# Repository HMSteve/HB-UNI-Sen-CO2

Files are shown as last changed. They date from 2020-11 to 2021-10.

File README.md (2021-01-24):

# HB-UNI-Sen-CO2

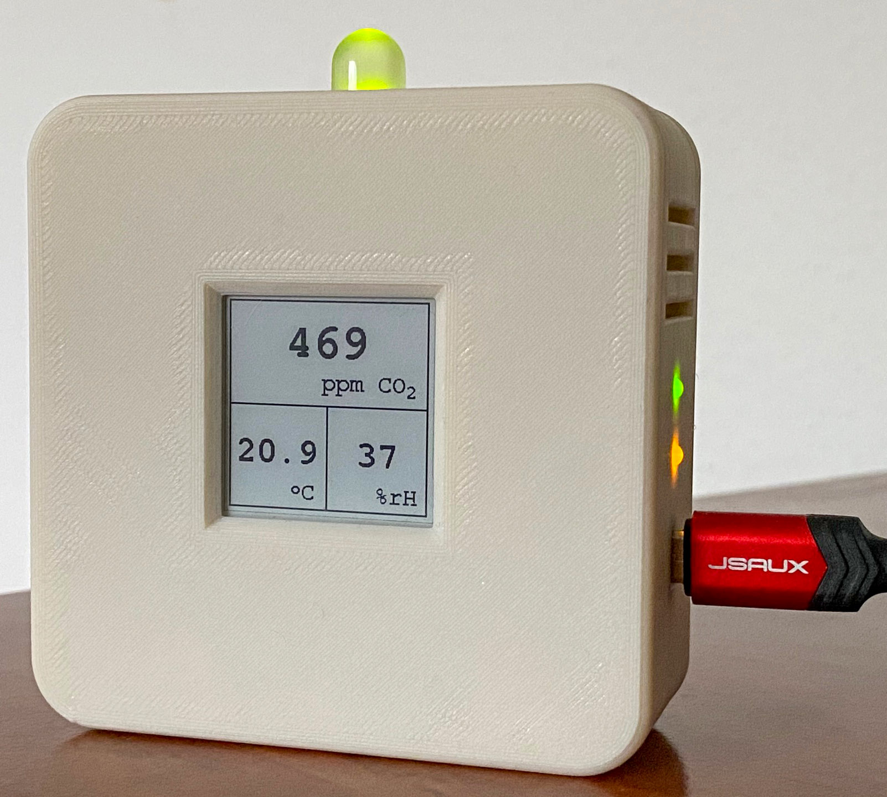
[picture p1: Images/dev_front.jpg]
HB-UNI-Sen-CO2


Eine AskSinPP-Implementierung eines Innenraum-Sensors mit dem NDIR-CO2-Sensor SCD30. Das Geraet kann regulaer in eine Homematic-Umgebung eingebunden werden und liefert Messwerte fuer die CO2-Konzentration, Temperatur, Lueftfeuchte und bei bestuecktem BME280 auch Luftdruck. Ebenso kann es abseits einer Homematic-Installation stand-alone als "CO2-Ampel" verwendet werden: Die Messwerte werden auf einem E-Paper-Display angezeigt und es kann eine Indikator-LED fuer die CO2-Konzentration zugeschaltet werden. Der Betrieb erfolgt mittels zweier AA-NiMH-Akkus, auf Li-Po/Li-Ionen-Akkus wurde unter Sicherheitsaspekten bewusst verzichtet. Eine Ladeschaltung mit Micro-USB-Buchse ist eingebaut. Ueber diese erfolgt eine Schnelladung mit 500mA sowie auf Wunsch parallel zu einer "Erhaltungsladung" die dauerhafte Versorgung des Sensors. Hierzu dient ein uebliches USB-Ladegeraet, das mind. 1A dauerhaft liefern koennen sollte.

## Platine

Auf der Platine sind drei I2C-Steckplaetze fuer Sensoren vorgesehen. Neben dem [Sensirion SCD30](https://www.sensirion.com/de/umweltsensoren/kohlendioxidsensor/kohlendioxidsensoren-co2/) bietet sich ein [4-poliges BME280-Modul](https://www.ebay.de/itm/BME280-Temperatur-Luftdruck-Feuchtigkeit-Sensor-I2C-1-8-5V-Modul/114603492524) zur Luftdruck-Kompensation an. Der Drucksensor ist auch in der Firmware vorgesehen. Der dritte Steckplatz ist aktuell frei.
Als Display findet ein [1.54" Waveshare-E-Paper-Modul](https://www.waveshare.com/1.54inch-e-Paper-Module.htm) Verwendung.

[Schaltplan](https://github.com/HMSteve/HB-UNI-Sen-CO2/blob/main/PCB/HB-Uni-Sen-CO2_Schematic.pdf)

[Stueckliste](https://github.com/HMSteve/HB-UNI-Sen-CO2/blob/main/PCB/HB_UNI_Sen_CO2_BOM.pdf)

Ein paar Fotos vom Aufbau:

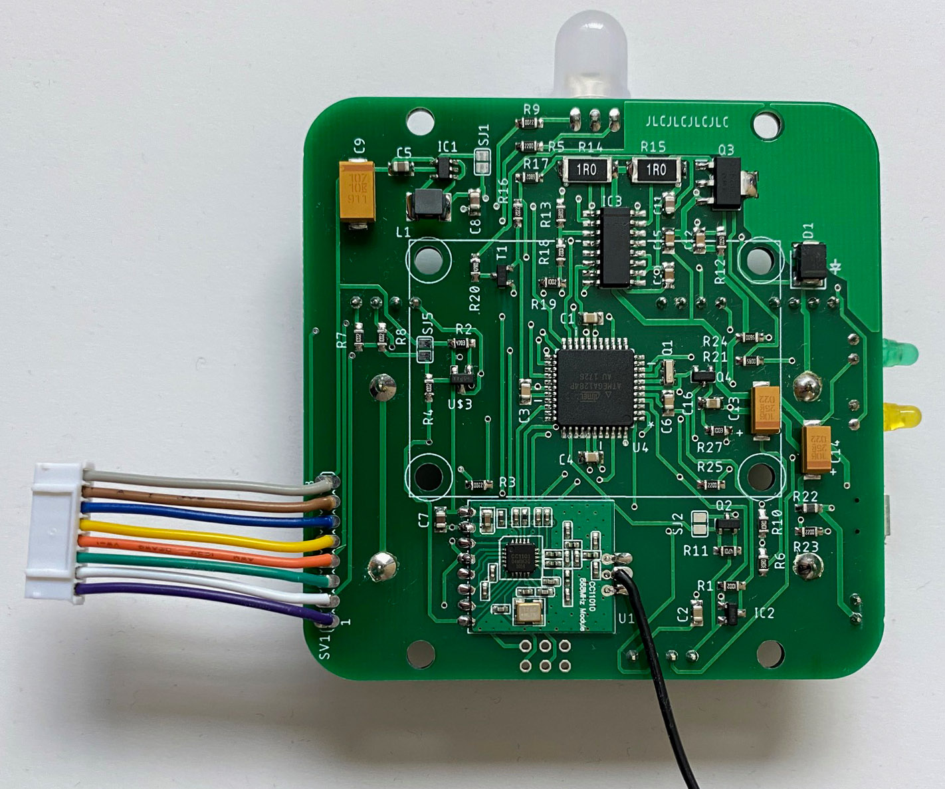
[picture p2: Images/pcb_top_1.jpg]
PCB Top


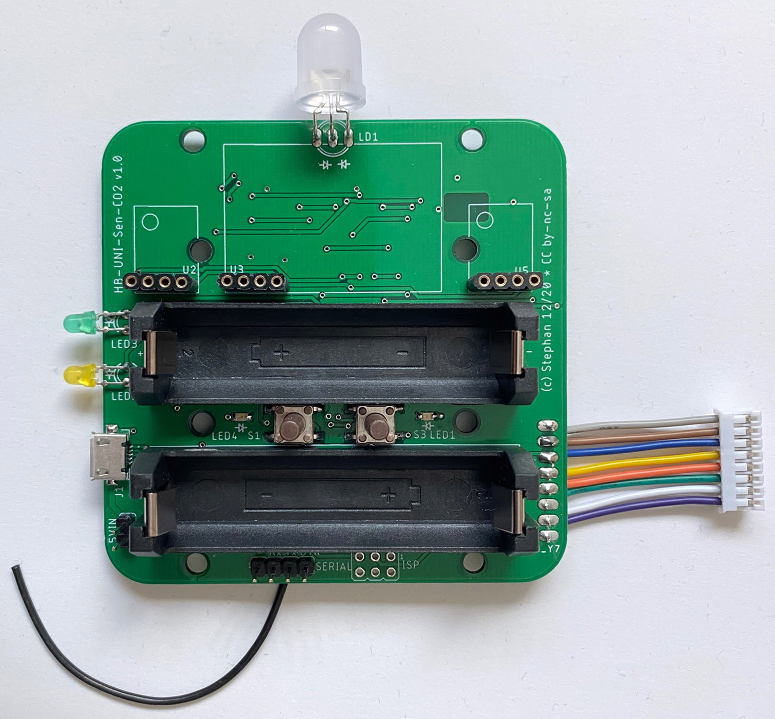
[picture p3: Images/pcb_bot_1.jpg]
PCB Bottom


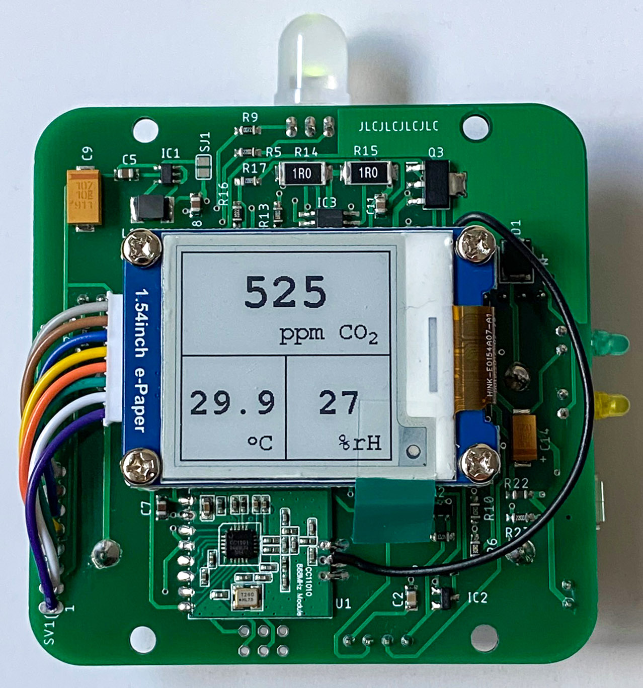
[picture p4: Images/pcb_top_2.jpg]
PCB Top 2


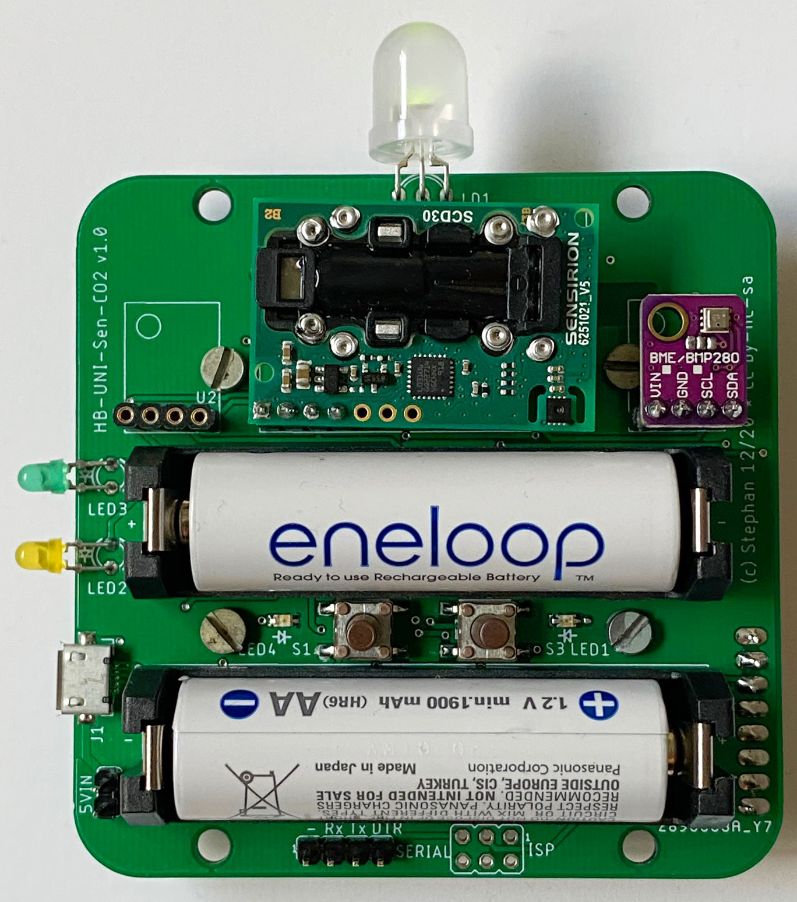
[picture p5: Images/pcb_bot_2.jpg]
PCB Bottom 2


Hinweis: Da leider das Displaymodul und nicht der aktive Displaybereich mittig auf der Platine angeordnet wurden, ist die Duo-LED vor dem Gehaeuseeinbau durch Zurechtbiegen der Anschluesse ca. 3mm versetzt zu bestuecken. Die 3mm-LEDs duerfen den Platinenrand nur wenig ueberragen, um den Einbau ins Gehaeuse zu ermoeglichen.

## Software

### Addon zur Geraeteunterstuetzung

Sofern noch nicht vorhanden oder nicht aktuell, ist das [Addon](https://github.com/HMSteve/SG-HB-Devices-Addon/raw/master/CCU_RM/sg-hb-devices-addon.tgz) auf der CCU zu installieren. Der Sensor benoetigt mindestens Version 1.23.

### Firmware

Es wird ein ATMega1284p verwendet, da der Speicherplatz des ATMega328p nicht ausreicht. Deshalb ist bei Nutzung der Arduino IDE zunaechst eine zusaetzliche sog. Boardverwalter-URL (https://mcudude.github.io/MightyCore/package_MCUdude_MightyCore_index.json) in den Voreinstellungen zu hinterlegen. Folgende Boardeinstellungen sind dann auszuwaehlen:

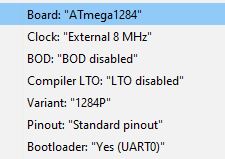
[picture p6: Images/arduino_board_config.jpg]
Boardeinstellungen


Danach kann der Bootloader geflashed werden.

Um die Firmware zu kompilieren, muessen sich die .ino sowie die .h Dateien im gleichen Verzeichnis befinden, das ./sensors-Verzeichnis darunter. Zudem muss eine Reihe von Bibliotheken ueber den Library Manager eingebunden werden:
- AskSinPP
- EnableInterrupt
- LowPower
- SparkFun SCD30 Arduino Library
- Adafruit BME280 Library
- GxEPD
- Adafruit GFX

Anschliessend sollte die Firmware problemlos kompilierbar und das Device nach dem Flashen anlernbar sein.

## Bedienung

Es gibt neben der AskSinPP-Config-Taste eine weitere Bedientaste. Ein kurzer Druck auf diese schaltet die Ampel-LED ein bzw. aus, ein langer Druck fuehrt zu einer forced calibration des SCD30. Hierzu sollte sich der Sensor bereits einige Minuten an der frischen Luft ohne nennenswerte Druckschwankungen durch Wind befunden haben. Der lange Tastendruck kalibriert dann den Sensor auf den im WebUI hinterlegten CO2-Referenzwert (im Freien ca. 410ppm). Die automatische Kalibrierung wird nicht verwendet auf Basis der These, dass ein Wegdriften der Auto-Kalibrierung bei nicht ausreichendem regelmaessigem Lueften problematischer ist als die Alterungsdrift nach forced calibration. Langzeitbeobachtungen hierzu fehlen mir jedoch.

Unterschreitet die Akkuspannung 2.2V, wird ein Warnsymbol im Display angezeigt und ein USB-Ladegerate sollte angeschlossen werden. Geschieht das nicht und die Spannung sinkt unter 2.0V, schaltet sich der Sensor zum Schutz vor Tiefentladung ab und zeigt dies an. Ein Reset (Wiedereinschalten) erfolgt automatisch beim Anschluss eines Ladegeraetes. Die gruene LED zeigt das Anliegen der Ladespannung, die gelbe den Schnelladevorgang. Es ist zu beachten, dass die Erwaermung beim Schnelladen natuerlich die Messwerte im Gehaeuse verfaelscht.

Die Schaltschwellen der Ampelfarben, die Hoehe ueber NN sowie ein vom SCD30-Temperaturmesswert zu subtrahierender Offset zur Korrektur der Anzeige koennen im WebUI konfiguriert werden.

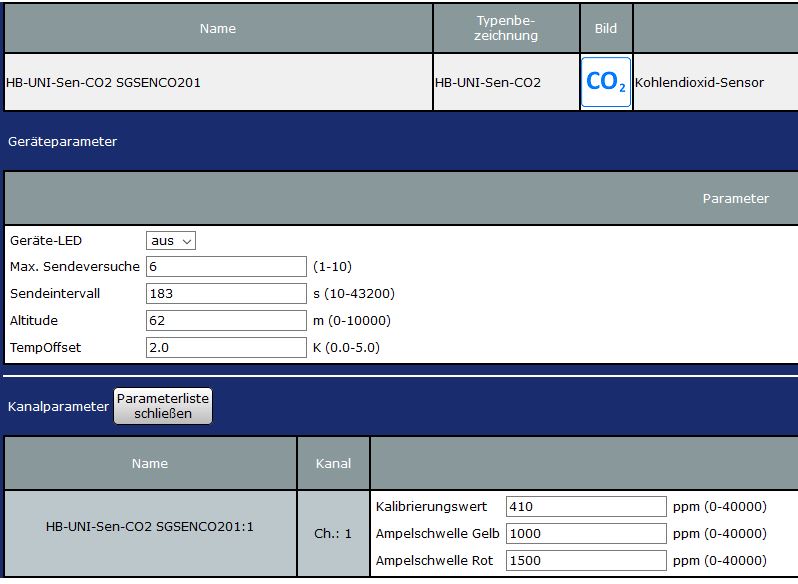
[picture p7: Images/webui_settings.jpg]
WebUI Settings


Die Messwerte werden dann so angezeigt:

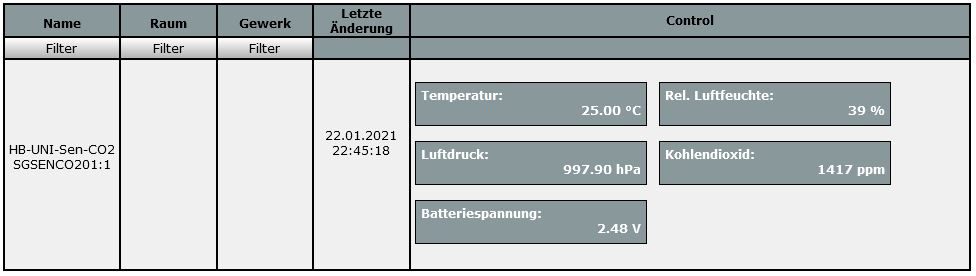
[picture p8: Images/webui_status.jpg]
WebUI Status


### Hinweise zum Energieverbrauch

Der SCD30 zieht einen nennenswerten Ruhestrom (mind. 5mA). Ein Power Cycling wird vom Hersteller nicht empfohlen, siehe [hier](https://github.com/HMSteve/HB-UNI-Sen-CO2/blob/main/Addl/CD_AN_SCD30_Low_Power_Mode_D2.pdf).
Damit ist fuer das Geraet bei der Voreinstellung einer Sensor-Abtastperiode von 16s eine Akkulaufzeit von hoechstens 5 Tagen zu erwarten. Das heisst, der mobile Betrieb waehrend eines oder einiger (Arbeits)tage ist problemslos moeglich. Der Dauerbetrieb sollte jedoch eher mit USB-Netzteil erfolgen. Dabei versorgt nach Ende der Schnelladung der von der MAX712-Ladeschaltung gelieferte, von R20 gemaess [Datenblatt MAX712](https://github.com/HMSteve/HB-UNI-Sen-CO2/blob/main/Addl/MAX712-MAX713.pdf) feinjustierte Erhaltungsladestrom das Device.  

Hier eine Messung zum Stromverbrauch:

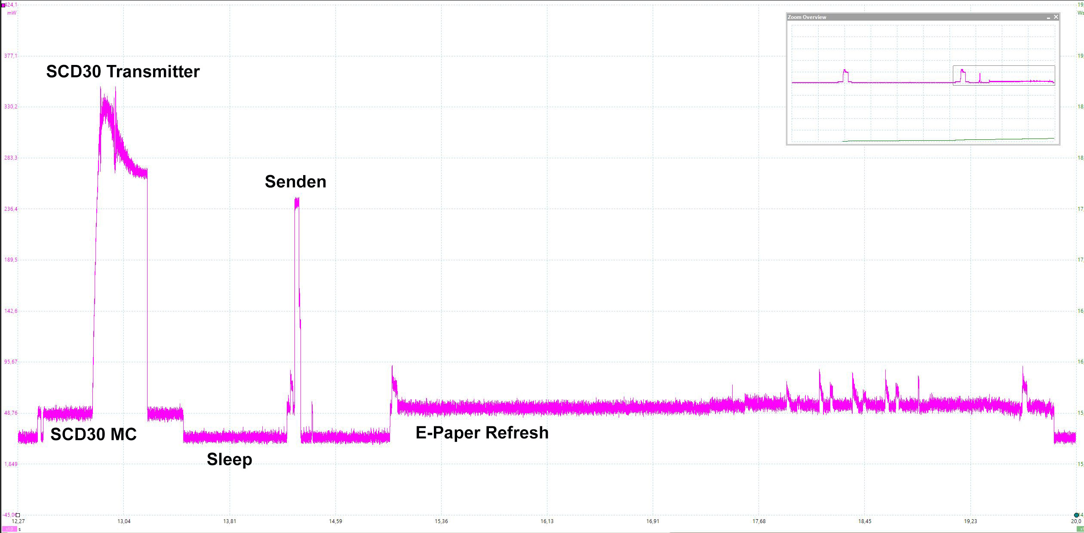
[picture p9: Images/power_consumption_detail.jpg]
Power Consumption Detail


Ein Excel-Workbook zum power budgeting findet sich [hier](https://github.com/HMSteve/HB-UNI-Sen-CO2/blob/main/Addl/BatteryBudgeting.xlsx).

## Gehaeuse

Zwischen Display und Platine sind vier zu druckende Abstandshuelsen einzusetzen. Das Gehaeuse stellt beim Drucken keine groesseren Herausforderungen. Die LED-Loecher sind ggf. mit 10.5mm bzw. 3.5mm aufzubohren, die Loecher im Boden mit 3mm.
Fuer die Befestigung der Platine sind [M3-Einpressmuttern](https://www.amazon.de/dp/B08BCRZZS3) vorgesehen. Die Befestigung der Platine im Gehaeuse erfolgt mit M3x10 Distanzbolzen. Die Rueckwand wird dann mit M3x10 Zylinderkopfschrauben an diesen befestigt.

## Disclaimer

Die Nutzung der hier veroeffentlichten Inhalte erfolgt vollstaendig auf eigenes Risiko und ohne jede Gewaehr.

## Lizenz

**Creative Commons BY-NC-SA**<br>
Give Credit, NonCommercial, ShareAlike

<br />This work is licensed under a <a rel="license" href="http://creativecommons.org/licenses/by-nc-sa/4.0/">Creative Commons Attribution-NonCommercial-ShareAlike 4.0 International License</a>.

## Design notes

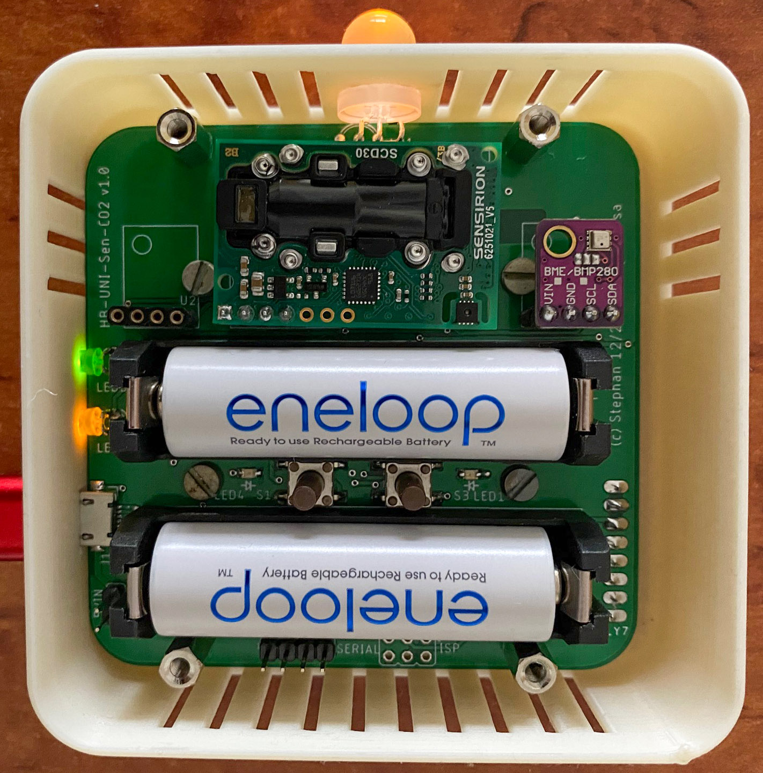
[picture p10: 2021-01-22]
Images/dev_int.jpg

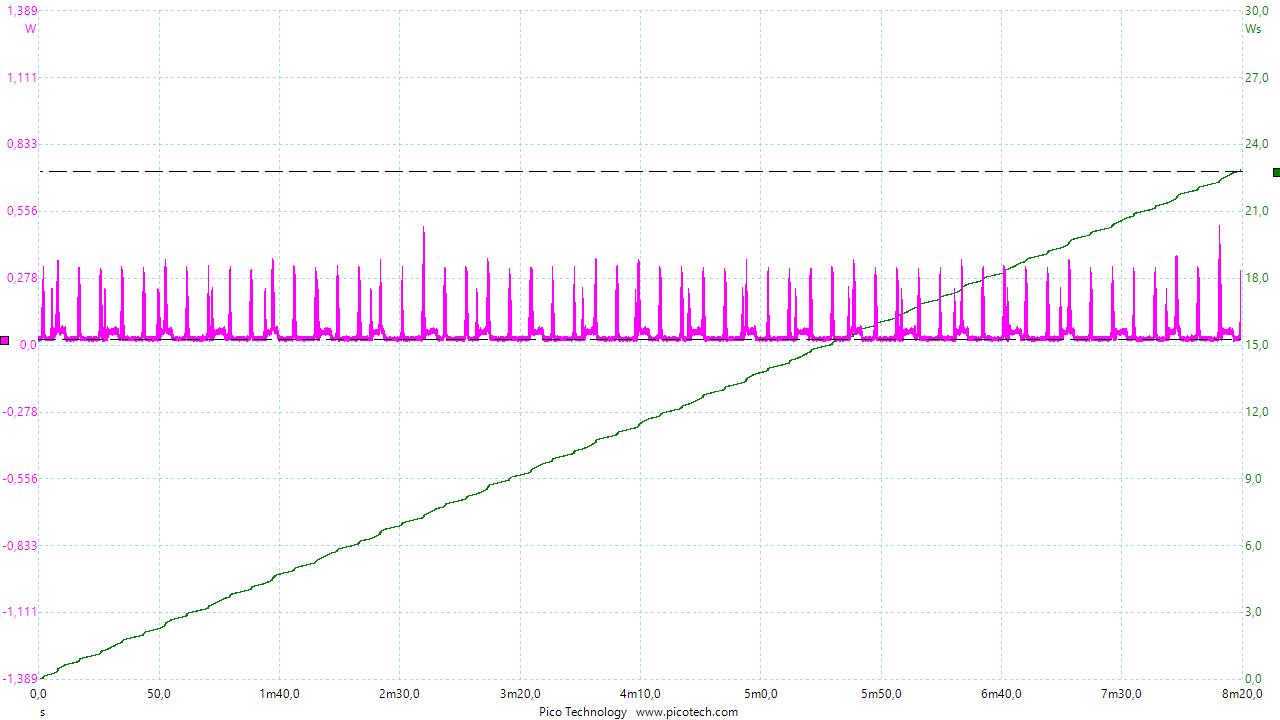
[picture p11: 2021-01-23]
Images/power_consumption_avg.jpg

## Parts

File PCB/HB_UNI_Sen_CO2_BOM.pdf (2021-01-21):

Qty | Value | Package | Parts
1 | ISP Header | ./. | ISP
6 | 100n | C0805K | C1, C2, C3, C4, C6, C16
3 | 10n | C0805K | C10, C12, C15
3 | 10u | C0805K | C5, C8, C11
1 | 1u | C0805K | C7
1 | CC1101-868MHz-Modul | CC1101-SMD2MM | U1
1 | LEDCHIPLED_0805 ge | CHIPLED_0805 | LED1
1 | LEDCHIPLED_0805 rt | CHIPLED_0805 | LED4
1 | CSTCE 8MHz | CSTCE | Q1
2 | 10u/25V Ta (Kemet T491) | CT6032 | C13, C14
1 | 100u/10V Ta (Kemet T494) | CT7343 | C9
1 | Vishay Schottky Diode VS-10BQ040 | DIOC4436X240N | D1
2 | SMD Kurzhubtaster 6x6x13mm | DTSM-6 | S1, S3
1 | Kingbright L-819EGW 10mm Duo-LED | DUOLED-C-10MM | LD1
2 | AA Batteriehalter | KEYSTONE 1015 | U$1, U$2
1 | Micro-USB-Buchse | Keystone 940 | J1
1 | Murata LQH43CN100K03L (10uH) | L4532P | L1
1 | LED3MM ge | LED3MM | LED2
1 | LED3MM gn | LED3MM | LED3
1 | 5Vin | MPE 087 2-pol | 5VIN
1 | serial | MPE 087 4-pol | SERIAL
2 | I2C_BREAKOUT_4P | MPE 115 4-pol | U2, U5
1 | SCD30 | MPE 115 4-pol | U3
1 | ATMEGA1284P-AU | QFP44 | U4
1 | 100k | R0805W | R27
6 | 10k | R0805W | R1, R4, R7, R8, R18, R19
1 | 10R | R0805W | R10
1 | 150R | R0805W | R12
1 | 200R | R0805W | R23
4 | 220R | R0805W | R3, R5, R9, R25
1 | 22k | R0805W | R16
1 | 30R | R0805W | R6
1 | 470k | R0805W | R2
1 | 4k7 | R0805W | R11
2 | 560R | R0805W | R21, R24
1 | 56R 0.33W | R0805W | R20
1 | 68k | R0805W | R17
1 | 6R8 | R0805W | R13
1 | Murata BLM21PG300SN1D Ferrit Bead | R0805W | R22
2 | 1R 1W | R2512W | R14, R15
1 | MAX712CSE | SO16 | IC3
1 | MCP111-270 | SOT23 | IC2
1 | SI2365 | SOT23 | U$3
1 | FMMT491 | SOT-23 | T1
2 | IRLML6344 | SOT-23 | Q2, Q4
1 | BDP950 | SOT230P700X170-4N | Q3
1 | MAX1724EZK33+T | SOT95P275X110-5N | IC1

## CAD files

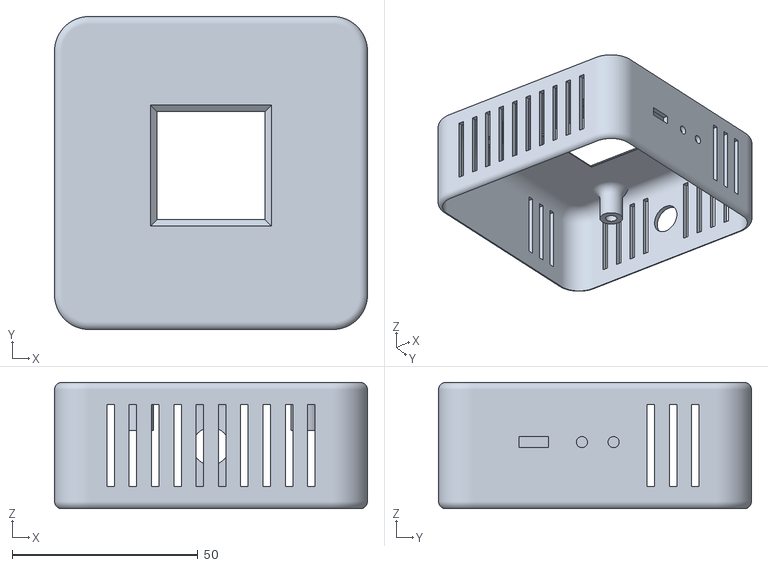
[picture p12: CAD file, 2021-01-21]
STL/Deckel.stl
84.2 x 84.2 x 34.0

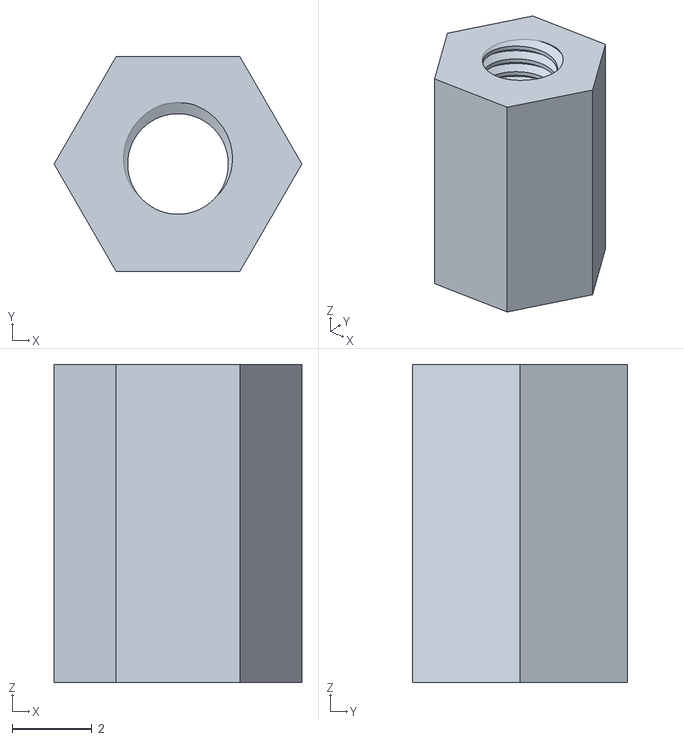
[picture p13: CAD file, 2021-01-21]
STL/AbstandshuelseM3x8.stl
6.24 x 5.40 x 8.00

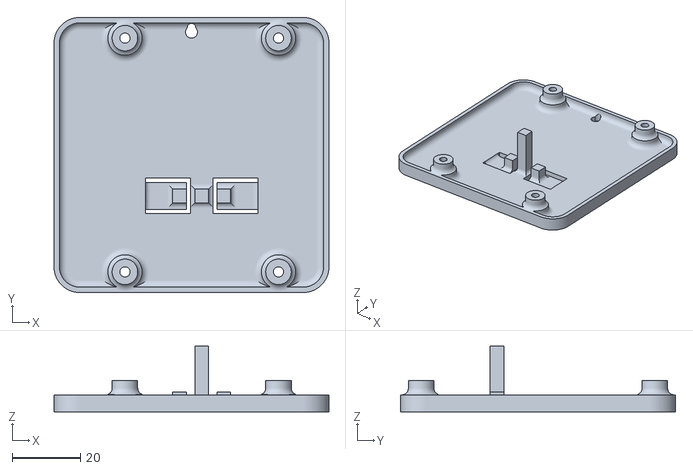
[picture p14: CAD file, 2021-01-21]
STL/Boden.stl
80.6 x 80.6 x 19.3

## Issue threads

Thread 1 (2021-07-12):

BOM und Centroid-Datei

Athemis, 2021-07-12:
Hallo,

an erster Stelle großes Lob und vielen Dank für das Zusammenstellen dieses Sensors! JLPCB bietet inzwischen für kleines Geld den Service an, die Leiterplatte einseitig mit Bauteilen zu bestücken. Gerade wenn man ein paar Sensoren "im Batch" bauen möchte und (wie ich) keinen Reflow-Ofen zur Hand hat, ist das eine Erleichterung, die vermutlich nicht nur ich gerne in Anspruch nehmen würde.

Bei der Bestellung benötigt man zusätzlich zu den Gerber-Files auch eine BOM (z.B. als CSV, die könnte man sich auch notfalls händisch aus dem PDF generieren) und ein Centroid File, welches die Positionierung und Orientierung der Bauteile enthält. Es wäre klasse, wenn Du beides ebenfalls dem Repo hinzufügen könntest!

Eine genaue Beschreibung gibt es hier: https://support.jlcpcb.com/category/78-smt-assembly
bzw. für [KiCAD](https://support.jlcpcb.com/article/84-how-to-generate-the-bom-and-centroid-file-from-kicad) oder [EagleCAD](https://support.jlcpcb.com/article/91-how-to-generate-the-bom-and-centroid-file-from-eaglecad).

Vielen Dank und beste Grüße

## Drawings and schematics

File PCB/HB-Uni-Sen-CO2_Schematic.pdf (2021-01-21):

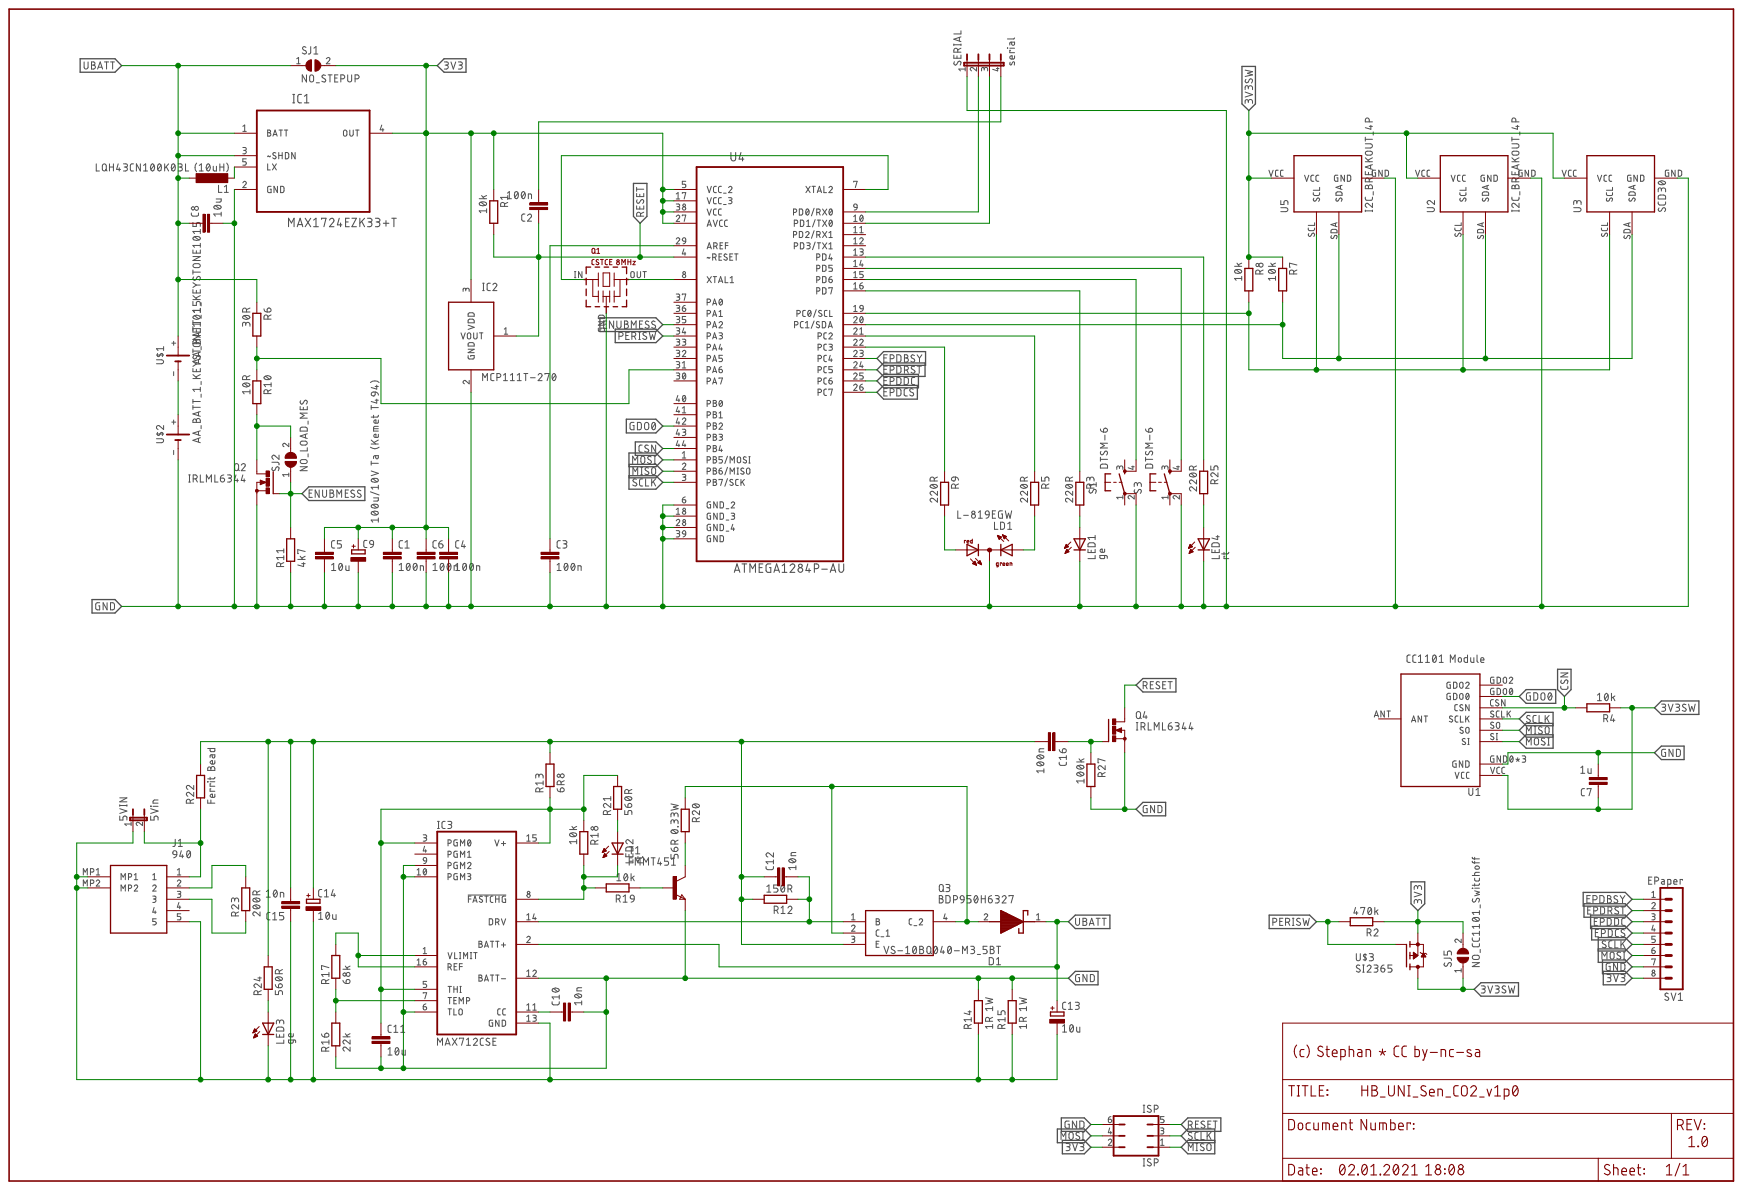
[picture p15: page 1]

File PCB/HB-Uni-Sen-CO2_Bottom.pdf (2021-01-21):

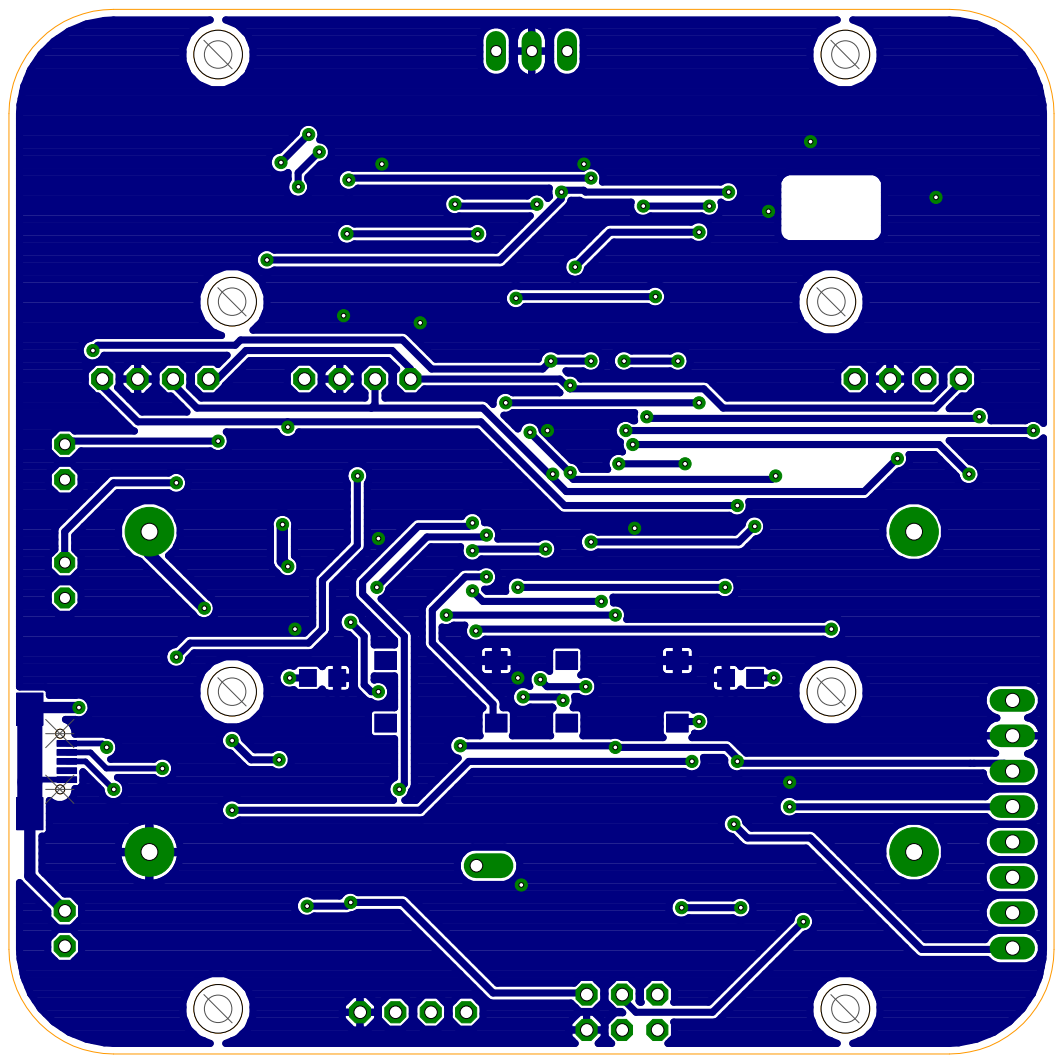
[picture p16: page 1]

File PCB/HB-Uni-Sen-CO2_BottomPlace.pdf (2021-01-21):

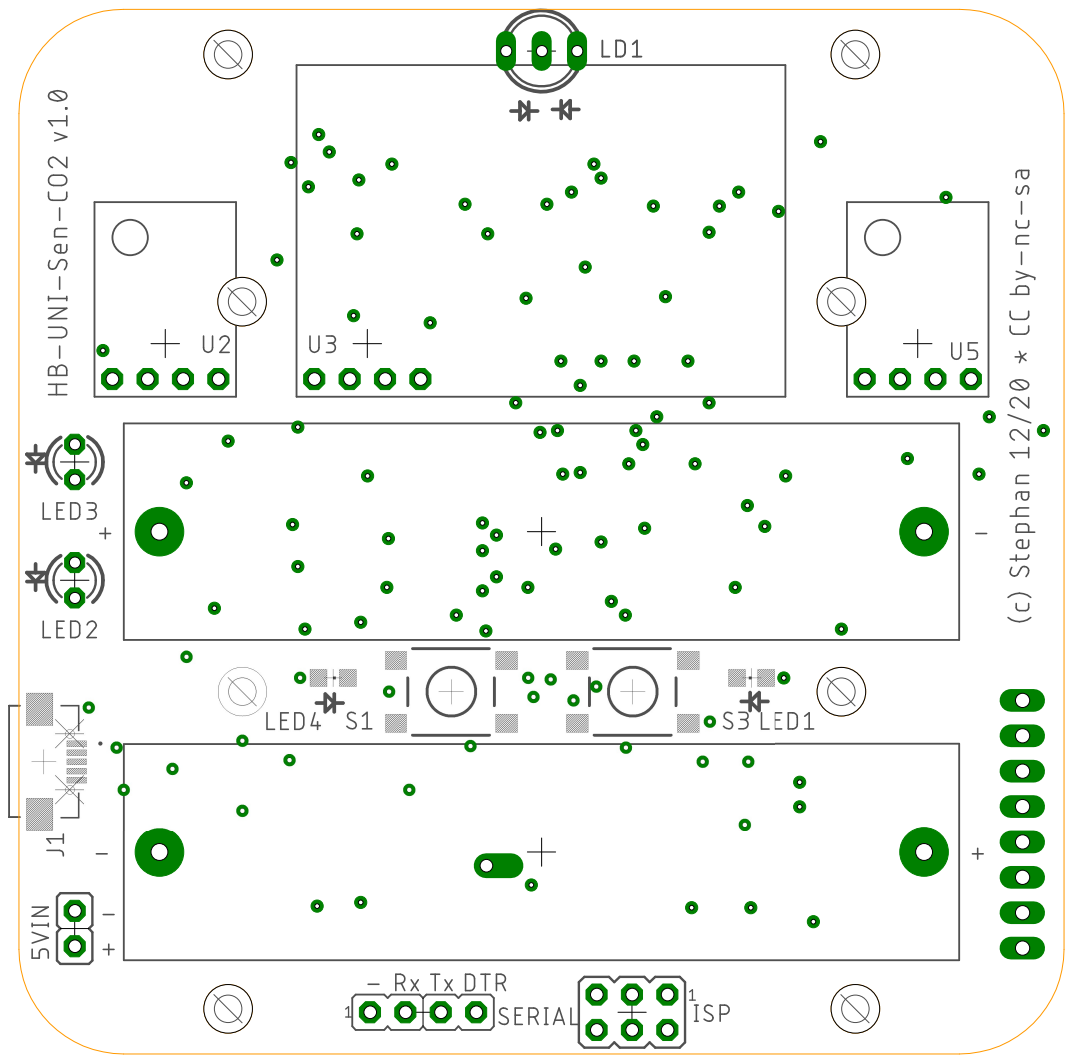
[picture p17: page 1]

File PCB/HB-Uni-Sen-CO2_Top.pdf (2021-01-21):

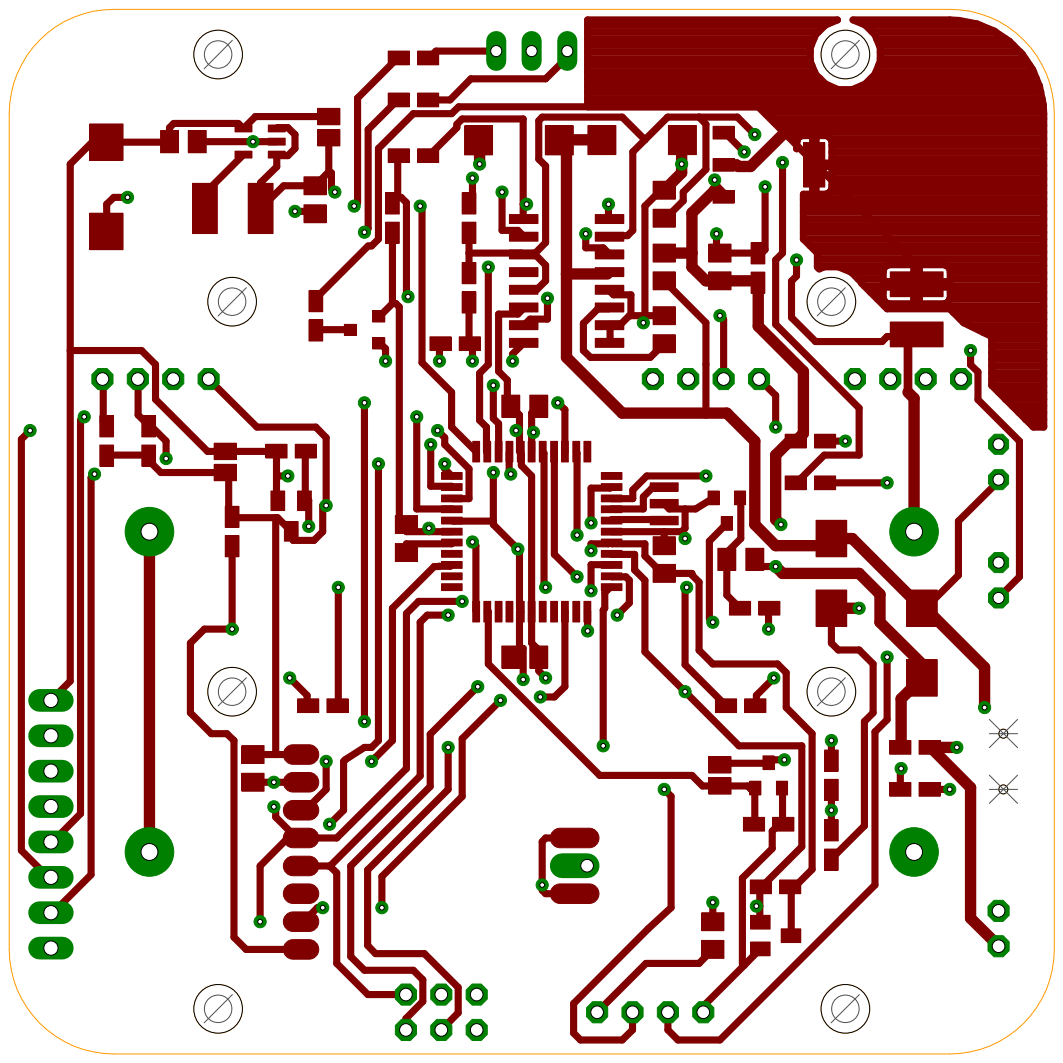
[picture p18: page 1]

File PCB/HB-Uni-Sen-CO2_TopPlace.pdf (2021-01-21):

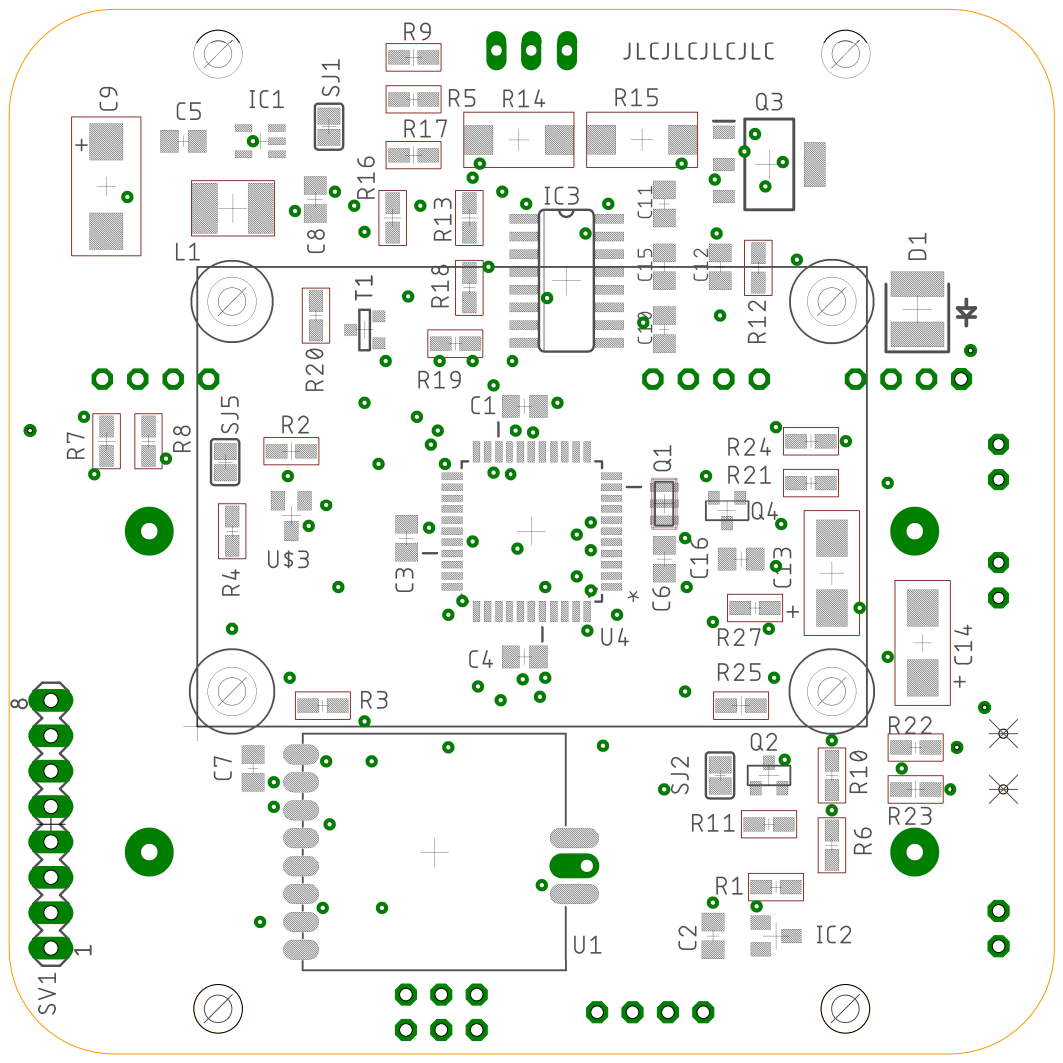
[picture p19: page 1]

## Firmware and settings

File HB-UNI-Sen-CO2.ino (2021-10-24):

//- -----------------------------------------------------------------------------------------------------------------------
// AskSin++
// 2016-10-31 papa Creative Commons - http://creativecommons.org/licenses/by-nc-sa/3.0/de/
// 2019-02-28 jp112sdl (Creative Commons)
//- -----------------------------------------------------------------------------------------------------------------------
// 2020-11-07 CO2 Sensor, HMSteve (cc)
//- -----------------------------------------------------------------------------------------------------------------------

//#define NDEBUG   // disable all serial debug messages  

#define EI_NOTEXTERNAL
//#define useBME280 //use pressure sensor for compensation

#define BAT_VOLT_LOW        22  // 2.2V for 2x Eneloop 
#define BAT_VOLT_CRITICAL   20  // 2.0V for 2x Eneloop

#include <EnableInterrupt.h>
#include <AskSinPP.h>
#include <LowPower.h>
#include <Register.h>
#include <MultiChannelDevice.h>
#include "sensors/Sens_SCD30.h"
#include "sensors/tmBattery.h"  //SG: added from Tom's UniSensor project
#if defined useBME280
  #include "sensors/Sens_BME280.h"
#endif
#include "EPDisplay.h"
#include "DuoLed.h"
#include "UserButton.h"


// Pin definitions Stephan's HB-UNI-Sen-CO2 Board v1.0
#define CC1101_CS_PIN        4
#define CC1101_GDO0_PIN      2
#define CC1101_SCK_PIN       7 
#define CC1101_MOSI_PIN      5 
#define CC1101_MISO_PIN      6 
#define LED_PIN             12              
#define LED2_PIN            15
#define DUOLED_GN_PIN       18
#define DUOLED_RT_PIN       19
#define CONFIG_BUTTON_PIN   14
#define USER_BUTTON_PIN     13 
#define CC1101_PWR_SW_PIN   27


#define PEERS_PER_CHANNEL 6
// tmBatteryLoad: sense pin A6, activation pin 26, Faktor = Rges/Rlow*1000, z.B. 10/30 Ohm, Faktor 40/10*1000 = 4000, 200ms Belastung vor Messung
// 1248p has 2.56V ARef, 328p has 1.1V ARef, so output needs to be scaled up
#define BATT_SENSOR tmBatteryLoad<A6, 26, (uint16_t)(4000.0*2.56/1.1), 200>  



// all library classes are placed in the namespace 'as'
using namespace as;

// define all device properties
const struct DeviceInfo PROGMEM devinfo = {
  {0xf8, 0x22, 0x01},     // Device ID
  "SGSENCO201",           // Device Serial
  {0xf8, 0x22},           // Device Model Indoor //orig 0xf1d1
  0x10,                   // Firmware Version
  as::DeviceType::THSensor, // Device Type
  {0x01, 0x00}            // Info Bytes
};




//Configure the used hardware
typedef AvrSPI<CC1101_CS_PIN, CC1101_MOSI_PIN, CC1101_MISO_PIN, CC1101_SCK_PIN> SPIType;
typedef Radio<SPIType, CC1101_GDO0_PIN> RadioType;
typedef StatusLed<LED_PIN> LedType;
typedef AskSin<LedType, BATT_SENSOR, RadioType> BaseHal;
typedef StatusLed<LED2_PIN> Led2Type;
typedef DuoLed<DUOLED_GN_PIN, DUOLED_RT_PIN> DuoLedType;


class Hal : public BaseHal {
  public:
    void init (const HMID& id) {
      BaseHal::init(id);
      // measure battery every a*b*c seconds
      battery.init(seconds2ticks(60UL * 30 * 1), sysclock);  
      battery.low(BAT_VOLT_LOW);
      battery.critical(BAT_VOLT_CRITICAL);
    }

    bool runready () {
      return sysclock.runready() || BaseHal::runready();
    }
} hal;


DEFREGISTER(Reg0, MASTERID_REGS, DREG_LEDMODE, DREG_TRANSMITTRYMAX, 0x20, 0x21, 0x22, 0x23, 0x24)
class SensorList0 : public RegList0<Reg0> {
  public:
    SensorList0(uint16_t addr) : RegList0<Reg0>(addr) {}

    bool updIntervall (uint16_t value) const {
      return this->writeRegister(0x20, (value >> 8) & 0xff) && this->writeRegister(0x21, value & 0xff);
    }
    uint16_t updIntervall () const {
      return (this->readRegister(0x20, 0) << 8) + this->readRegister(0x21, 0);
    }
    
    bool altitude (uint16_t value) const {
      return this->writeRegister(0x22, (value >> 8) & 0xff) && this->writeRegister(0x23, value & 0xff);
    }
    uint16_t altitude () const {
      return (this->readRegister(0x22, 0) << 8) + this->readRegister(0x23, 0);
    }

    bool tempOffset10 (uint8_t value) const {
      return this->writeRegister(0x24, value & 0xff);
    }
    uint16_t tempOffset10 () const {
      return this->readRegister(0x24, 0);
    }    


    void defaults () {
      clear();
      ledMode(1);
      transmitDevTryMax(3);     
      updIntervall(183); //seconds
      altitude(62); //meters
      tempOffset10(0); //temperature offset for SCD30 calib: 15 means 1.5K
    }
};



DEFREGISTER(Reg1, 0x01, 0x02, 0x03, 0x04, 0x05, 0x06, 0x07)
class SensorList1 : public RegList1<Reg1> {
  public:
    SensorList1 (uint16_t addr) : RegList1<Reg1>(addr) {}

    bool co2CalibRef (uint16_t value) const {
      return this->writeRegister(0x01, (value >> 8) & 0xff) && this->writeRegister(0x02, value & 0xff);
    }
    
    uint16_t co2CalibRef () const {
      return (this->readRegister(0x01, 0) << 8) + this->readRegister(0x02, 0);
    }

    bool co2StateAmber (uint16_t value) const {
      return this->writeRegister(0x03, (value >> 8) & 0xff) && this->writeRegister(0x04, value & 0xff);
    }
    
    uint16_t co2StateAmber () const {
      return (this->readRegister(0x03, 0) << 8) + this->readRegister(0x04, 0);
    }

    bool co2StateRed (uint16_t value) const {
      return this->writeRegister(0x05, (value >> 8) & 0xff) && this->writeRegister(0x06, value & 0xff);
    }
    
    uint16_t co2StateRed () const {
      return (this->readRegister(0x05, 0) << 8) + this->readRegister(0x06, 0);
    }

    bool co2NoGreen (uint16_t value) const {
      return this->writeRegister(0x07, value & 0xff);
    }
    
    uint16_t co2NoGreen () const {
      return this->readRegister(0x07, 0);
    }    

    void defaults () {
      clear();
      co2CalibRef(410); //410ppm in fresh air
      co2StateAmber(1000);     
      co2StateRed(2000); 
      co2NoGreen(0);       
    }
};



class WeatherEventMsg : public Message {
  public:
    void init(uint8_t msgcnt, int16_t temp, uint8_t humidity, uint16_t pressureNN, uint16_t co2, uint16_t volt, bool batlow) {
      uint8_t t1 = (temp >> 8) & 0x7f;
      uint8_t t2 = temp & 0xff;
      if ( batlow == true ) {
        t1 |= 0x80; // set bat low bit
      }
      // BIDI|WKMEUP every 20th msg
      uint8_t flags = BCAST;
      if ((msgcnt % 20) == 1) {
          flags = BIDI | WKMEUP;
      }      
      // Message Length (first byte param.): 11 + payload. Max. payload: 17 Bytes (https://www.youtube.com/watch?v=uAyzimU60jw)
      Message::init(18, msgcnt, 0x70, flags, t1, t2);
      pload[0] = humidity & 0xff;
      pload[1] = (pressureNN >> 8) & 0xff;           
      pload[2] = pressureNN & 0xff;          
      pload[3] = (co2 >> 8) & 0xff;           
      pload[4] = co2 & 0xff;         
      pload[5] = (volt >>8) & 0xff;
      pload[6] = volt & 0xff;      
    }
};




class WeatherChannel : public Channel<Hal, SensorList1, EmptyList, List4, PEERS_PER_CHANNEL, SensorList0>, public Alarm {
    WeatherEventMsg     msg;
    bool                firstMsg = true;
    uint16_t            millis;
    uint16_t            pressureAmb = 1013; //mean pressure at sea level in hPa
    uint16_t            pressureNN = 0; //dummy value to be returned if no sensor measurement
    uint16_t            co2 = 0;
    uint16_t            temp10 = 0;
    uint8_t             humidity = 0;
    DuoLedType          trafficLight; 
    bool                trafficLightEnabled = false;    
    ePaperType          ePaper;
    Sens_SCD30          scd30;        
#if defined useBME280
    Sens_BME280         bme280;
#endif       
       

  public:
    WeatherChannel () : Channel(), Alarm(10), millis(0) {}
    
    virtual ~WeatherChannel () {}

    virtual void trigger (__attribute__ ((unused)) AlarmClock& clock) {
      // reactivate for next measure
      tick = delay();
      clock.add(*this);

      // measure
      #if defined useBME280
        bme280.measure(this->device().getList0().altitude());
        pressureAmb = bme280.pressure()/10;
        pressureNN = bme280.pressureNN();
      #endif
      scd30.measure(pressureAmb);
      
      // suppress potentially erranous first CO2 measurements after reset due to connecting charger
      if (!firstMsg) {
        co2 = scd30.carbondioxide();
        temp10 = scd30.temperature() - this->device().getList0().tempOffset10();
        humidity = scd30.humidity();        
      
        DPRINT("Temp x10 / Hum / PressureNN x10 / PressureAmb / Batt x10 / CO2 = ");
        DDEC(temp10 / 10);DPRINT(" / ");
        DDEC(humidity);DPRINT(" / ");
        DDEC(pressureNN);DPRINT(" / ");
        DDEC(pressureAmb);DPRINT(" / ");     
        DDEC(device().battery().current() / 10);DPRINT(" / ");
        DDECLN(co2);

        uint8_t msgcnt = device().nextcount();
        msg.init( msgcnt, temp10, humidity, pressureNN, co2, device().battery().current() / 10, device().battery().low());
        if (msg.flags() & Message::BCAST) 
        {
          device().broadcastEvent(msg, *this);
        }
        else
        {
          device().sendPeerEvent(msg, *this);
        }
        
        DisplayData.co2 = co2;
        DisplayData.temperature = temp10 / 10.0;
        DisplayData.humidity = humidity;   
        DisplayData.lowbatt = device().battery().low();    
        ePaper.mustUpdateDisplay(true);
        ePaper.setRefreshAlarm(500);      
       
        setTrafficLight();
      };
      firstMsg = false;
    }


    uint32_t delay () {
      return seconds2ticks(this->device().getList0().updIntervall());
    }
    
    void setup(Device<Hal, SensorList0>* dev, uint8_t number, uint16_t addr) {
      Channel::setup(dev, number, addr);
      
      uint16_t scd30SamplingInterval = this->device().getList0().updIntervall() / 5;
      if (scd30SamplingInterval < 1) {scd30SamplingInterval = 1;}       
      if (scd30SamplingInterval > 30) {scd30SamplingInterval = 30;}
      DPRINT("SCD30 sampling interval : ");DDECLN(scd30SamplingInterval);
      scd30.init(device().getList0().altitude(), this->device().getList0().tempOffset10(), scd30SamplingInterval, false);
      
      #if defined useBME280
        bme280.init();
      #endif
      
      trafficLight.init();
      
      sysclock.add(*this);
    }

    uint8_t status () const {
      return 0;
    }

    uint8_t flags () const {
      return 0;
    }


    bool forceCalibSCD30()
    {
      return(scd30.setForcedRecalibrationFactor(this->getList1().co2CalibRef()));
    }


    bool setSCD30SamplingInterval()
    {
      uint16_t scd30SamplingInterval = this->device().getList0().updIntervall() / 5;
      if (scd30SamplingInterval < 1) {scd30SamplingInterval = 1;}      
      if (scd30SamplingInterval > 30) {scd30SamplingInterval = 30;}
      return(scd30.setSamplingInterval(scd30SamplingInterval));
    }


    void stopSCD30()
    {
      scd30.stop_measurements();   
    }


    void setTrafficLight()
    {
      if (trafficLightEnabled)
      {
        if ((co2 <= this->getList1().co2StateAmber()) and (this->getList1().co2NoGreen())) trafficLight.setOff();
        if ((co2 <= this->getList1().co2StateAmber()) and !(this->getList1().co2NoGreen())) trafficLight.setGreen();
        if ((co2 > this->getList1().co2StateAmber()) and (co2 <= this->getList1().co2StateRed())) trafficLight.setAmber();
        if (co2 > this->getList1().co2StateRed()) trafficLight.setRed();
      }
      else
      {
        trafficLight.setOff();
      }
    }

    bool toggleTrafficLight()
    {
      trafficLightEnabled = !trafficLightEnabled;
      setTrafficLight();
      return(trafficLightEnabled);
    }
};




class SensChannelDevice : public MultiChannelDevice<Hal, WeatherChannel, 1, SensorList0> {
  public:
    typedef MultiChannelDevice<Hal, WeatherChannel, 1, SensorList0> TSDevice;
    Led2Type    led2;
    
    SensChannelDevice(const DeviceInfo& info, uint16_t addr) : TSDevice(info, addr) 
    {
      led2.init();
    }
    
    virtual ~SensChannelDevice () {}

    virtual void configChanged () {
      TSDevice::configChanged();
      this->channel(0).setSCD30SamplingInterval();
      DPRINTLN("* Config Changed       : List0");
      DPRINT(F("* LED Mode             : ")); DDECLN(this->getList0().ledMode());    
      DPRINT(F("* Sendeversuche        : ")); DDECLN(this->getList0().transmitDevTryMax());                   
      DPRINT(F("* SENDEINTERVALL       : ")); DDECLN(this->getList0().updIntervall());
      DPRINT(F("* Hoehe ueber NN       : ")); DDECLN(this->getList0().altitude());
      DPRINT(F("* Temp Offset x10      : ")); DDECLN(this->getList0().tempOffset10());   
         
    }
};



SensChannelDevice sdev(devinfo, 0x20);
ConfigButton<SensChannelDevice> cfgBtn(sdev);
UserButton<SensChannelDevice> usrBtn(sdev);


void setup () {
  //SG: switch on MOSFET to power CC1101 and sensors
  pinMode(CC1101_PWR_SW_PIN, OUTPUT);
  digitalWrite (CC1101_PWR_SW_PIN, LOW);
  //init ePaper display
  //display.init(); //not done here because v2 of Waveshare display draws about continuous 3mA via Reset pin
  DINIT(57600, ASKSIN_PLUS_PLUS_IDENTIFIER);
  sdev.init(hal);
  buttonISR(cfgBtn, CONFIG_BUTTON_PIN);
  buttonISR(usrBtn, USER_BUTTON_PIN);  
  sdev.initDone();
  //DPRINT("List0 dump: "); sdev.getList0().dump();
}


void loop() {
  bool worked = hal.runready();
  bool poll = sdev.pollRadio();
  if ( worked == false && poll == false ) {
    if (hal.battery.critical()) {
      // this call will never return
      DPRINTLN("!!!Shutting down due to critical battery voltage!!!");
      sdev.channel(0).stopSCD30(); 
      display.init();          
      display.drawPaged(EmptyBattDisplay);
      pinMode(EPD_RST_PIN,INPUT); 
      //wait a bit to let paged epd refresh finish
      delay(5000);
      pinMode(CC1101_PWR_SW_PIN, INPUT);
      hal.activity.sleepForever(hal);      
    }    
    // if nothing to do - go to sleep
    hal.activity.savePower<Sleep<>>(hal);
  }
}

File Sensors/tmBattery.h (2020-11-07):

//---------------------------------------------------------
// tmBattery
// 2019-05-14 Tom Major (Creative Commons)
// https://creativecommons.org/licenses/by-nc-sa/4.0/
// You are free to Share & Adapt under the following terms:
// Give Credit, NonCommercial, ShareAlike
// +++
// AskSin++ 2016-10-31 papa Creative Commons
//---------------------------------------------------------

#ifndef _TM_BATTERY_H_
#define _TM_BATTERY_H_

#include <Debug.h>
#include <AlarmClock.h>

#ifdef ARDUINO_ARCH_AVR

#define ADCMUX_ADCMASK ((1 << MUX3) | (1 << MUX2) | (1 << MUX1) | (1 << MUX0))
#define ADCMUX_REFMASK ((1 << REFS1) | (1 << REFS0))

#define ADCMUX_REF_AREF ((0 << REFS1) | (0 << REFS0))
#define ADCMUX_REF_AVCC ((0 << REFS1) | (1 << REFS0))
#define ADCMUX_REF_RESV ((1 << REFS1) | (0 << REFS0))
#define ADCMUX_REF_VBG ((1 << REFS1) | (1 << REFS0))

#if defined(__AVR_ATmega32U4__) || defined(__AVR_ATmega1280__) || defined(__AVR_ATmega2560__) || defined(__AVR_ATmega644P__)                         \
    || defined(__AVR_ATmega1284P__)
#define ADCMUX_ADC_VBG ((1 << MUX4) | (1 << MUX3) | (1 << MUX2) | (1 << MUX1) | (0 << MUX0))
#else
#define ADCMUX_ADC_VBG ((1 << MUX3) | (1 << MUX2) | (1 << MUX1) | (0 << MUX0))
#endif
#else
#error INVALID ARCHITEKTURE
#endif

namespace as {

//---------------------------------------------------------
class tmBattery : public Alarm {
    uint8_t  m_Low, m_Critical;
    uint16_t m_LastValue;
    uint32_t m_Period;

public:
    tmBattery()
        : Alarm(0)
        , m_Low(0)
        , m_Critical(0)
        , m_LastValue(0)
        , m_Period(0)
    {
    }
    virtual ~tmBattery() {}

    virtual void trigger(AlarmClock& clock)
    {
        m_LastValue = voltage();
        tick        = m_Period;
        clock.add(*this);
    }

    uint16_t current() const { return m_LastValue; }

    bool critical() const
    {
        return ((m_LastValue / 100) < m_Critical);    // low/critical values have to be in default AskSinPP 100mV resolution
    }

    void critical(uint8_t value)
    {
        m_Critical = value;
        DPRINT(F("Battery set crit: "));
        DDECLN(m_Critical);
    }

    bool low() const { return ((m_LastValue / 100) < m_Low); }    // low/critical values have to be in default AskSinPP 100mV resolution

    void low(uint8_t value)
    {
        m_Low = value;
        DPRINT(F("Battery set low:  "));
        DDECLN(m_Low);
    }

    void init(uint32_t period, AlarmClock& clock)
    {
        // enable ADC, prescaler 128 = 62.5kHz ADC clock @8MHz (range 50..1000 kHz)
        ADCSRA      = (1 << ADEN) | (1 << ADPS2) | (1 << ADPS1) | (1 << ADPS0);
        ADCSRB      = 0;
        m_LastValue = voltage();
        m_Period    = period;
        tick        = m_Period;
        clock.add(*this);
    }

    void setIdle() {}
    void unsetIdle() {}

protected:
    uint16_t measure(uint16_t preDelayTime)
    {
        delay(preDelayTime);
        // messure 4 times
        uint16_t adc = 0;
        for (int i = 0; i < 4; i++) {
            ADCSRA |= (1 << ADSC);    // start conversion
            uint8_t timeout = 50;
            while (ADCSRA & (1 << ADSC)) {
                delayMicroseconds(10);
                timeout--;
                if (timeout == 0) {
                    return 0;
                }
            }
            adc += (ADC & 0x3FF);
            // DDECLN(ADC);
        }
        if ((adc & 0x03) >= 2) {    // rounding
            return (adc >> 2) + 1;
        } else {
            return (adc >> 2);
        }
    }

private:
    virtual uint16_t voltage()
    {
        // setup reference and input each time, just in case other SW modules have changed this
        ADMUX &= ~(ADCMUX_REFMASK | ADCMUX_ADCMASK);
        //ADMUX |= ADCMUX_REF_AVCC;      // select AVCC as reference
        ADMUX |= ADCMUX_ADC_VBG;       // select bandgap as input
        uint16_t adc = measure(50);    // load CVref 100nF, 5*Tau = 25ms
        if (adc) {
            // read Bandgap against AVCC:
            // ADC = Vin * 1024 / Vref -> Vref = Vin * 1024 / ADC
            // -> AVcc = Vbg * 1024 / ADC
            uint32_t avcc = 1100UL * 1024 / adc;
            DPRINT(F("tmBattery Voltage: "));
            DDECLN(avcc);
            return (uint16_t)avcc;
        } else {
            DPRINT(F("tmBattery Error"));
            return 0;
        }
    }
};

//---------------------------------------------------------
template <uint8_t SENSPIN, uint8_t ACTIVATIONPIN, uint16_t FACTOR> class tmBatteryResDiv : public tmBattery {
    // FACTOR: Rges/Rlow*1000, z.B. Teiler 470k/100k, Faktor 570k/100k*1000 = 5700

public:
    tmBatteryResDiv()
        : tmBattery()
    {
    }
    virtual ~tmBatteryResDiv() {}

    void init(uint32_t period, AlarmClock& clock)
    {
        pinMode(ACTIVATIONPIN, INPUT);    // disable resistor divider
        pinMode(SENSPIN, INPUT);          // input
        digitalWrite(SENSPIN, LOW);       // pull-up off
        tmBattery::init(period, clock);
    }

private:
    virtual uint16_t voltage()
    {
        // setup reference and input each time, just in case other SW modules have changed this
        ADMUX &= ~(ADCMUX_REFMASK | ADCMUX_ADCMASK);
        ADMUX |= ADCMUX_REF_VBG;                 // select bandgap as reference
        ADMUX |= ((SENSPIN - PIN_A0) & 0x0F);    // select SensePin as input

        pinMode(ACTIVATIONPIN, OUTPUT);
        digitalWrite(ACTIVATIONPIN, LOW);         // enable resistor divider
        uint16_t adc = tmBattery::measure(50);    // load CVref 100nF, 5*Tau = 25ms
        pinMode(ACTIVATIONPIN, INPUT);            // disable resistor divider

        if (adc) {
            // read SensePin against Bandgap:
            // ADC = Vin * 1024 / Vref -> Vin = Vref * ADC / 1024 (* resistor factor)
            uint32_t vbat = 11UL * adc * FACTOR / 1024 / 10;
            //DPRINT("adc: ");
            //DDECLN(adc);
            DPRINT(F("tmBatteryResDiv Voltage: "));
            DDECLN(vbat);
            return (uint16_t)vbat;
        } else {
            DPRINT(F("tmBatteryResDiv Error"));
            return 0;
        }
    }
};

//---------------------------------------------------------
template <uint8_t SENSPIN, uint8_t ACTIVATIONPIN, uint16_t FACTOR, uint16_t LOADTIME> class tmBatteryLoad : public tmBattery {
    // FACTOR: Rges/Rlow*1000, z.B. Teiler 10/30 Ohm, Faktor 40/10*1000 = 4000
    uint16_t m_LoadTime;    // Zeit für Aktivierung der Last in ms, Range 0..2000ms
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

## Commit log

2020-11-16 forced calib button added
2020-11-23 2 decimal places for batt voltage
2021-01-21 doc update
    [AbstandshuelseM3x8.stl, Boden.stl, Deckel.stl]
2021-01-23 some clean-up, batt budgeting added
    [BatteryBudgeting.xlsx]
2021-10-24 EPD reset pin current bug addressed
    [EPDisplay.h, HB-UNI-Sen-CO2.ino]
